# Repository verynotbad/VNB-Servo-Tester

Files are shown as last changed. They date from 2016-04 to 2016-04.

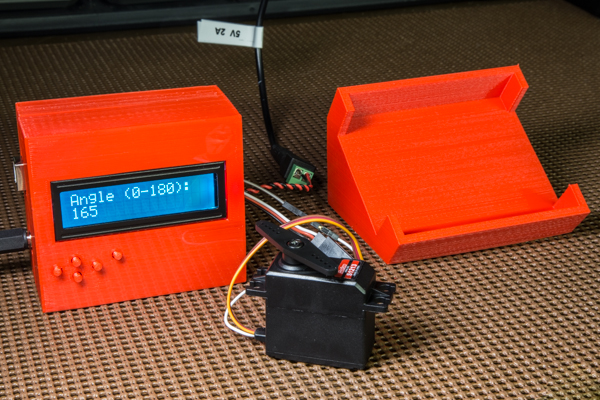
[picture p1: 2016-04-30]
Photos/VNB-Servo-Tester-10.jpg

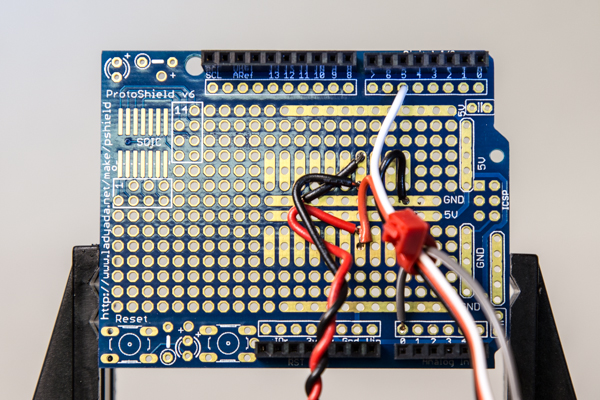
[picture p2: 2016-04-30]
Photos/VNB-Servo-Tester-28.jpg

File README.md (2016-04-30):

# VNB-Servo-Tester

For full details and assembly instructions, visit:
http://verynotbad.tech/projects/servo-tester-calibrator-with-arduino

alt-tag

Using an Arduino UNO, create a interactive device that can test hobby servos, let you calibrate your servo's microcontroller code (e.g. Arduino Sketches) by helping you find the minimum and maximum Pulse Width Modulation (PWM) settings, and even display the internal position of the servo (if your servo is equipped with an analog feedback line).  This project also has instructions and models for 3D Printing an enclosure for your device, letting you create a tool that no makerspace should be without.

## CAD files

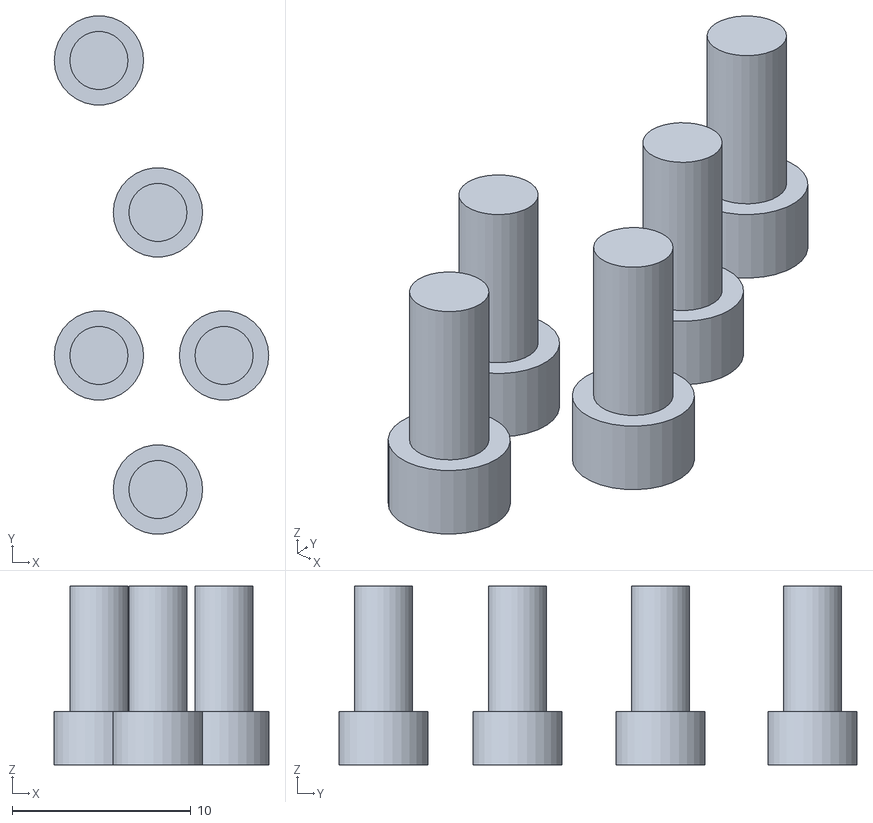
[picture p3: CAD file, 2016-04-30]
3D Model/Enclosure-Buttons.stl
12.0 x 29.0 x 10.0

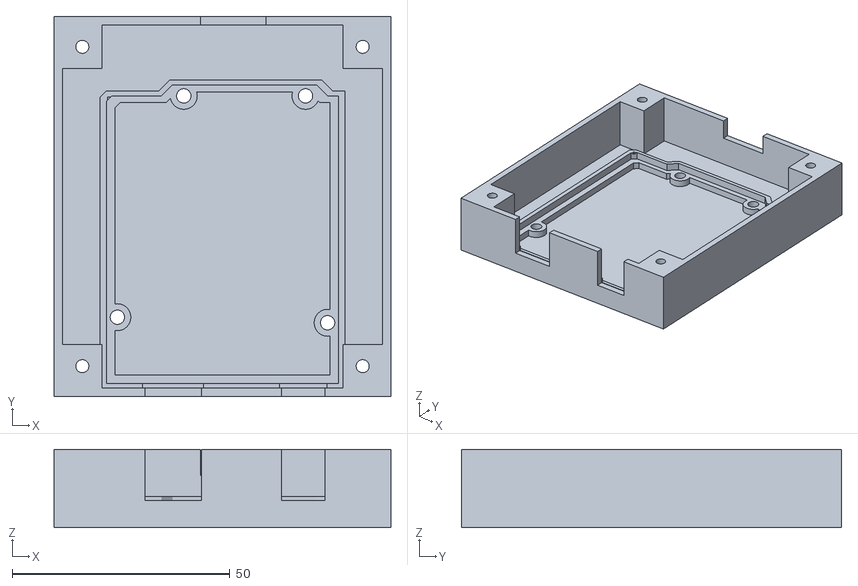
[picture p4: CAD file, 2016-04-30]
3D Model/Enclosure-Bottom.stl
77.3 x 87.3 x 18.0

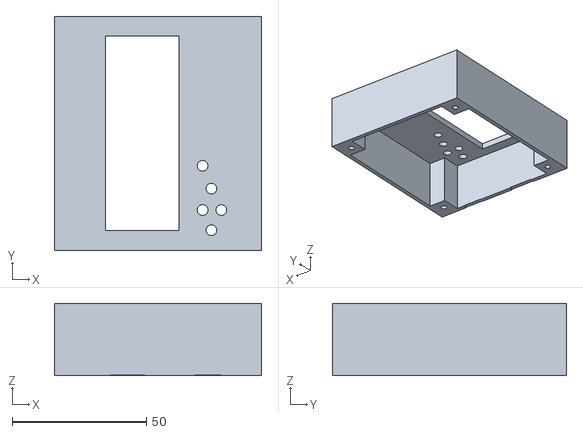
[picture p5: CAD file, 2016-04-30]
3D Model/Enclosure-Top.stl
77.3 x 87.3 x 27.0

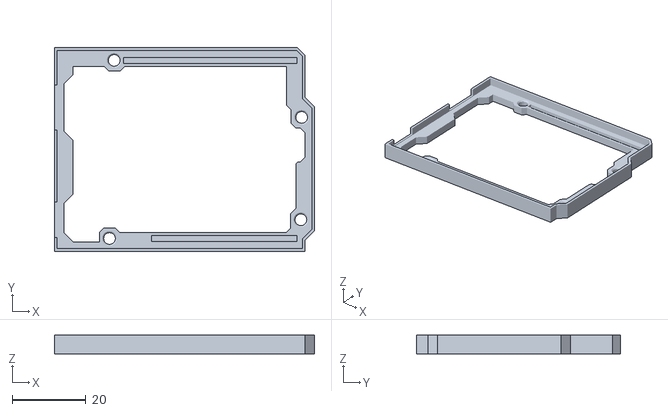
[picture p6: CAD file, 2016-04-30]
3D Model/Arduino_Bumper_0006.stl
70.5 x 55.2 x 5.08

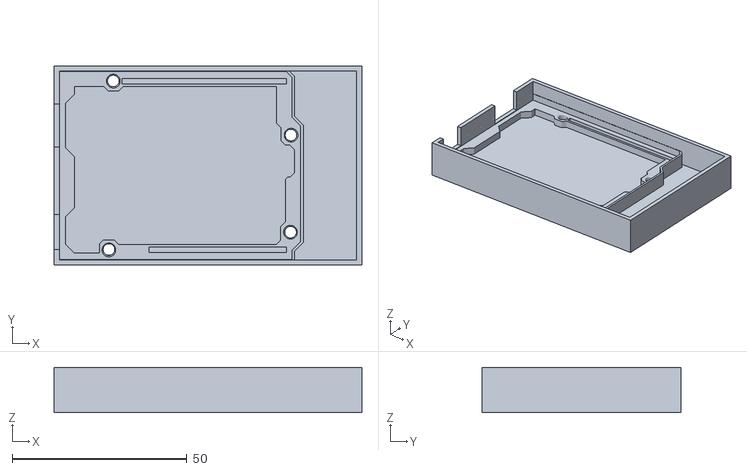
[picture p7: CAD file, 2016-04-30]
3D Model/Servo-Tester-Enclosure.stl
88.0 x 57.0 x 13.0

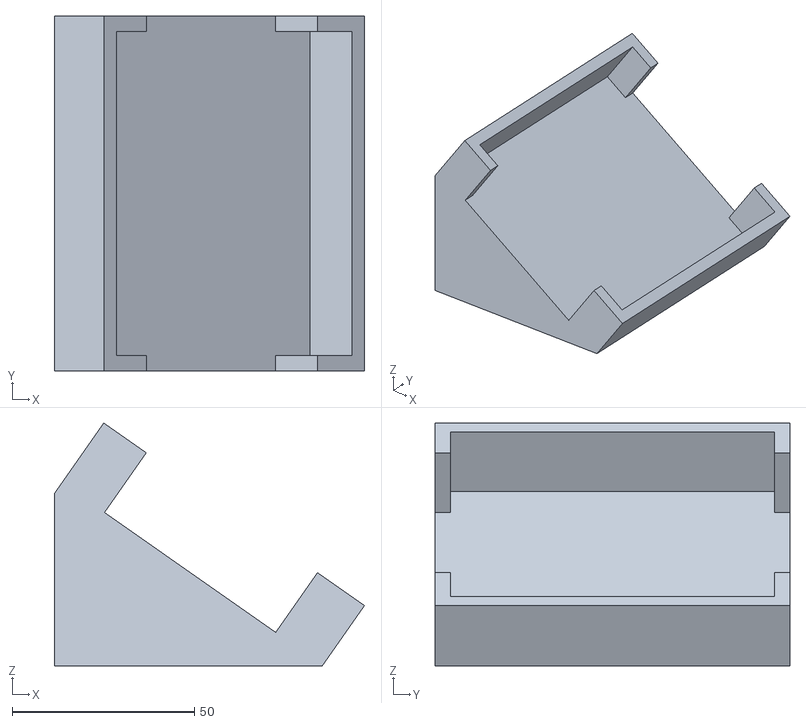
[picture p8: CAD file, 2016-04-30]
3D Model/Servo-Tester-Cradle.stl
85.1 x 97.3 x 66.7

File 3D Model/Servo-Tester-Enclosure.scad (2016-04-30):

use <MCAD/shapes.scad>
include <arduino.scad>

$fn = 30;

wallHeight = 36;

// ----------------------------------------------
// -- Visibility
// ----------------------------------------------

SHOW_ELECTRONICS			= false;

SHOW_TOP 					= false;
SHOW_BOTTOM 				= false;
SHOW_PUSHBUTTONS			= true;

SHOW_CRADLE					= false;

// ----------------------------------------------
// -- Base Parameters
// ----------------------------------------------
wallThickness		= 2.0;
baseThickness		= 3.0;

bottomHeight		= 18.0;

enclosureGapX		= 10.0;
enclosureGapY		= 1.0;

fastenerHoleD		= 3.3;
fastenerSupportX	= 9.0;
fastenerSupportY	= 10.0;

pushButtonH			= 10.0;
pushButtonZ			= 37.5;

bumperOffsetZ		= -2.1;
boardMountingHoleZ	= abs(bumperOffsetZ) + baseThickness + 2;


unoSize = boardDimensions(UNO);
electronicsLengthY = 81.3;
enclosureSizeX = unoSize[0] + (enclosureGapX + wallThickness)*2;
enclosureSizeY = electronicsLengthY + (enclosureGapY + wallThickness)*2;
//enclosureSize = [enclosureSizeX, enclosureSizeY, 0];

offsetX = (wallThickness + enclosureGapX) * -1;
offsetY = (wallThickness + enclosureGapY) * -1;

servoConnectorOpening = [15, 10, 6.1];


echo("Enclosure Size:");
echo("X: ", enclosureSizeX);
echo("Y: ", enclosureSizeY);


// ------------------------------------------------------------
// -- Model Root
// ------------------------------------------------------------

unoSize = boardDimensions(UNO);

	union()
	{

		if (SHOW_ELECTRONICS)
		{
			electronics();
		}

		difference()
		{
			union()
			{
				if (SHOW_TOP)
				{
					translate([0,0,0.1])
					enclosureTop(electronicsLengthY=81.3, topHeight=27, bottomHeight=bottomHeight);
				}

				if (SHOW_BOTTOM)
				{
					translate([0,0,0])
					enclosureBottom(electronicsLengthY=81.3, height=bottomHeight);
				}

				if (SHOW_CRADLE)
				{
					translate([0,0,0])
					enclosureCradle();
				}
			}
			
			
			//enclosureOpenings(height=bottomHeight);



			//arduinoMountingHoles();
			//enclosureOpenings();
			
		}
	}




	
if (SHOW_PUSHBUTTONS)
{
	color("Orange")
	translate([0, 0, pushButtonZ])
	lcdShield(pcb=false, display=false, buttons=false, btnHoleD=4.0, btnHoles=false, resetHole=false, screenHole=false, pushButtons=true, pushButtonH=pushButtonH);
}








// -----------------------------------------------------------------
// -- Modules
// -----------------------------------------------------------------

module enclosureTop(electronicsLengthY, topHeight=15, bottomHeight=10)
{

	enclosureSize = [enclosureSizeX, enclosureSizeY, topHeight];
	cutoutSize    = [enclosureSizeX-(wallThickness*2), enclosureSizeY-(wallThickness*2), topHeight];

	offsetX = (wallThickness + enclosureGapX) * -1;
	offsetY = (wallThickness + enclosureGapY) * -1;
	offsetZ = bottomHeight - baseThickness + bumperOffsetZ;


	difference()
	{
		union()
		{
			difference()
			{
				// -- Outer Walls
				translate([offsetX, offsetY, offsetZ])
				cube(enclosureSize);

				// -- Center Cutout
				translate([offsetX + wallThickness, offsetY + wallThickness, offsetZ - baseThickness])
				cube(cutoutSize);

			}

				// -- Top/Bottom Fastener Support Columns
				fastenerColumns(height=topHeight, offsetZ=offsetZ);
		}

		components( boardType = UNO, component = USB, extension = 5, offset = 0.5);
		components( boardType = UNO, component = POWER, extension = 5, offset = 0.5);

		translate([0, 0, offsetZ])
		lcdShield(pcb=false, display=false, buttons=false, btnHoleD=4.0, btnHoles=true, resetHole=false, screenHole=true);

		fastenerHoles(height=topHeight-2, offsetZ=offsetZ-1, d=3.0);
	}






}


module enclosureBottom(electronicsLengthY, height=10)
{
				translate([0,0,bumperOffsetZ])
				bumper(UNO);
	
/*
	unoSize = boardDimensions(UNO);

	enclosureSizeX = unoSize[0] + (enclosureGapX + wallThickness)*2;
	enclosureSizeY = electronicsLengthY + (enclosureGapY + wallThickness)*2;
*/

	enclosureSize = [enclosureSizeX, enclosureSizeY, height];
	cutoutSize    = [enclosureSizeX-(wallThickness*2), enclosureSizeY-(wallThickness*2), height];

	offsetX = (wallThickness + enclosureGapX) * -1;
	offsetY = (wallThickness + enclosureGapY) * -1;
	offsetZ = -1 * baseThickness + bumperOffsetZ;

	difference()
	{
		union()
		{
			difference()
			{		
				// -- Outer Walls
				translate([offsetX, offsetY, offsetZ])
				cube(enclosureSize);

				// -- Center Cutout
				translate([offsetX + wallThickness, offsetY + wallThickness, offsetZ + baseThickness])
				cube(cutoutSize);


			}

			// -- Top/Bottom Fastener Support Columns
			fastenerColumns(height=height, offsetZ=offsetZ);

		}

		components( boardType = UNO, component = USB, extension = 5, offset = 0.5);
		components( boardType = UNO, component = POWER, extension = 5, offset = 0.5);

		// -- Hole for Servo Connectors
		translate([unoSize[0]/2-5, 81.0, height+offsetZ-servoConnectorOpening[2] + 0.1])
		cube(servoConnectorOpening);


		fastenerHoles(height=height+2, offsetZ=offsetZ-1, d=3.0);

		// -- Arduino Mounting Holes
			for(i = boardHoles[UNO] ) 
			{
    			translate([i[0], i[1], boardMountingHoleZ*-1])
    			cylinder(d=3.3, h=boardMountingHoleZ);
  			}

	}


	
}


module enclosureCradle()
{
	enclosureSize = [enclosureSizeX, enclosureSizeY, 100];

	offsetX = (wallThickness + enclosureGapX) * -1;
	offsetY = (wallThickness + enclosureGapY) * -1;
	offsetZ = -1 * baseThickness + bumperOffsetZ;

	cradleHeight    = 60.0;
	baseHeight	 	= 30;
	wallThickness 	= 5.0;
	cutoutDepth 	= baseHeight-20.0;
	cutoutGap		= 0.75;
	sideCutoutX		= enclosureSizeX-20;
	sideCutoutOffset= 10;

	cutoutDepthAdder = 15;

	rotate([0,35,0])
	difference() 
	{
		union()
		{ 
			// -- Cradle
			color("Red")
			translate([offsetX-wallThickness, offsetY-wallThickness, offsetZ-cutoutDepth])
			rotate([0,0,0])
			cube([enclosureSize[0]+(wallThickness*2), enclosureSize[1]+(wallThickness*2), baseHeight-cutoutDepthAdder], center=false);

			rotate([0,-35,0])
			intersection() 
			{
			
				color("Red")
				translate([offsetX - enclosureSize[0], offsetY-wallThickness, cradleHeight*-1+3])
				rotate([0,0,0])
				cube([enclosureSize[0]*2, enclosureSize[1]+(wallThickness*2), cradleHeight], center=false);

				color("Red")
				rotate([0,35,0])
				translate([offsetX-wallThickness, offsetY-wallThickness, offsetZ-cutoutDepth-100])
				cube([enclosureSize[0]+(wallThickness*2), enclosureSize[1]+(wallThickness*2), 110], center=false);

				translate([-27.5,-50,-80])
				cube([100,200,100]);

			}


		}

		color("Orange")
		translate([offsetX-cutoutGap, offsetY-cutoutGap, offsetZ-cutoutDepthAdder])
		rotate([0,0,0])
		cube([enclosureSize[0]+(cutoutGap*2), enclosureSize[1]+(cutoutGap*2), 100], center=false);

		// -- Side Cutouts for Wires
		color("Orange")
		translate([offsetX-cutoutGap + sideCutoutOffset, offsetY-cutoutGap-enclosureSize[1]/2, offsetZ-cutoutDepthAdder])
		rotate([0,0,0])
		cube([sideCutoutX, enclosureSize[1]*2+(cutoutGap*2), 100], center=false);



	}


}


module fastenerColumns(height, offsetZ)
{
	offsetX = (wallThickness + enclosureGapX) * -1;
	offsetY = (wallThickness + enclosureGapY) * -1;
	//offsetZ = -1 * baseThickness + bumperOffsetZ;

	supportXL = enclosureGapX*-1;
	supportXR = enclosureSizeX + offsetX - fastenerSupportX - wallThickness;
	supportYB = enclosureGapY*-1;
	supportYT = enclosureSizeY + offsetY - fastenerSupportY - wallThickness;

	// -- Top/Bottom Fastener Support Columns
	translate([supportXL, supportYB, offsetZ])
	cube([fastenerSupportX, fastenerSupportY, height]);

	translate([supportXL,supportYT, offsetZ])
	cube([fastenerSupportX, fastenerSupportY, height]);

	translate([supportXR, supportYB, offsetZ])
	cube([fastenerSupportX, fastenerSupportY, height]);

	translate([supportXR,supportYT, offsetZ])
	cube([fastenerSupportX, fastenerSupportY, height]);

}

module fastenerHoles(height, offsetZ=0, d=3.0)
{
	offsetX = (wallThickness + enclosureGapX) * -1;
	offsetY = (wallThickness + enclosureGapY) * -1;
	//offsetZ = -1 * baseThickness + bumperOffsetZ;

	supportXL = enclosureGapX*-1 + fastenerSupportX/2;
	supportXR = enclosureSizeX + offsetX - fastenerSupportX - wallThickness + fastenerSupportX/2;
	supportYB = enclosureGapY*-1 + fastenerSupportY/2;
	supportYT = enclosureSizeY + offsetY - fastenerSupportY - wallThickness + fastenerSupportY/2;


	translate([supportXL, supportYB, offsetZ])
	cylinder(d=d, h=height);

	translate([supportXL, supportYT, offsetZ])
	cylinder(d=d, h=height);

	translate([supportXR, supportYB, offsetZ])
	cylinder(d=d, h=height);

	translate([supportXR, supportYT, offsetZ])
	cylinder(d=d, h=height);

}


module electronics()
{
	// -- Arduino Board
	translate([0,0,0])
	arduino(UNO);

	// -- Prototype Shield
	translate([0,0,13.0])
	union()
	{
		color("SteelBlue")
		boardShape(UNO);

		components( boardType = UNO, component = HEADER_F );
	}

	// -- LCD Shield
	translate([0, 0, 25.3])
	lcdShield();
}
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

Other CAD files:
3D Model/pins.scad
3D Model/arduino.scad

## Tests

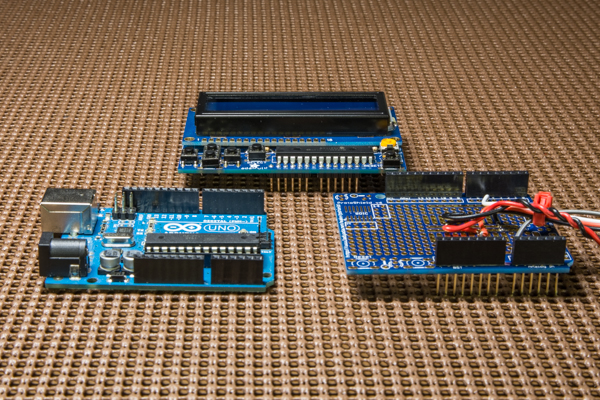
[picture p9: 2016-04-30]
Photos/VNB-Servo-Tester-34.jpg

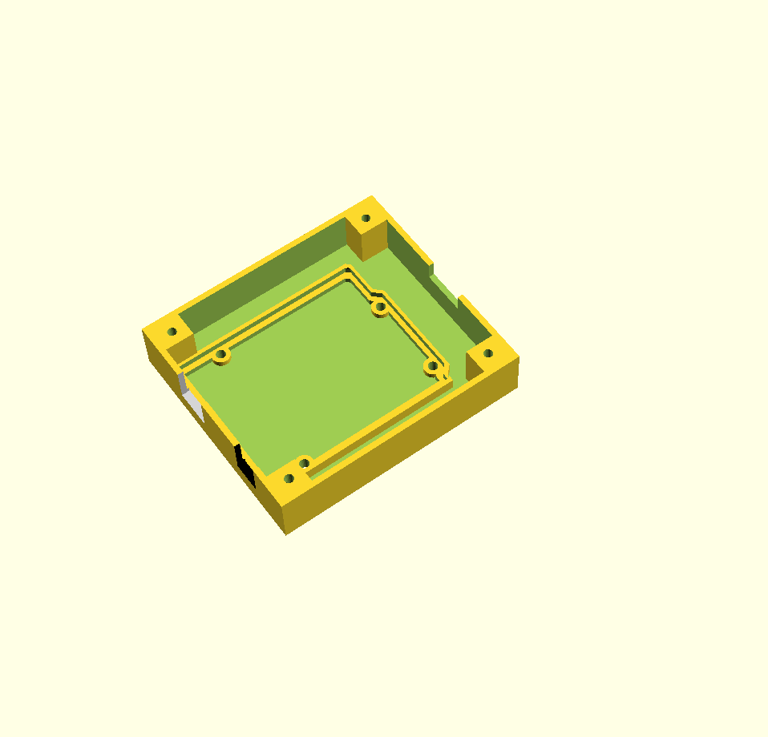
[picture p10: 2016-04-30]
Docs/Servo Tester - 3D Bottom.png

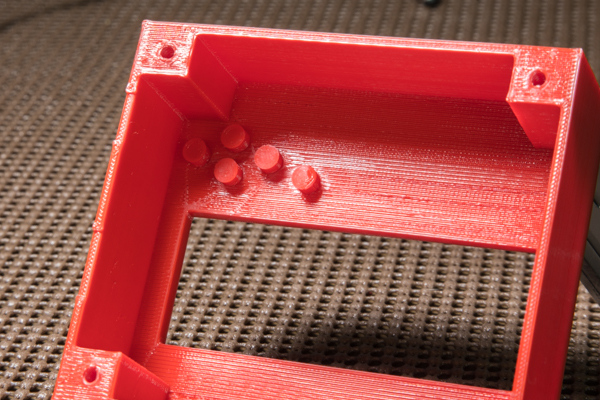
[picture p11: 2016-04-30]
Photos/VNB-Servo-Tester-33.jpg

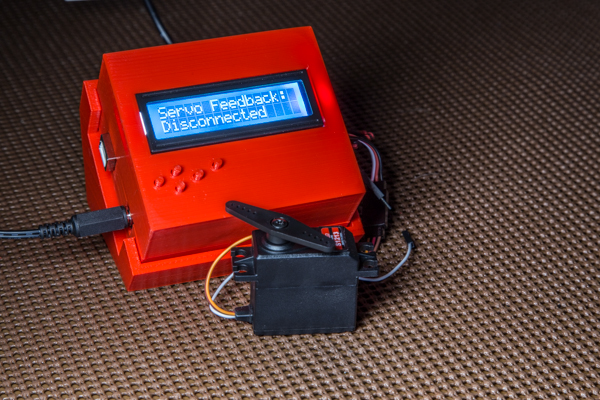
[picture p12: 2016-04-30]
Photos/VNB-Servo-Tester-8.jpg

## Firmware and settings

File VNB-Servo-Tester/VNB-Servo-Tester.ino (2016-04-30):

/**********************************************
 * Servo Tester
 * Copyright (c) 2016 Very Not Bad Prototypes
 * All Rights Reserved
 * 
 * http://www.verynotbad.tech
 * 
 * This code is a Servo Tester using an
 * Arduino Microcontroller and an Adafruit
 * LCD Shield.
 * 
 * Tests the following for hobby servos: 
 *    - PWM Min/Max
 *    - Feedback Values
 *    - Angles
 *    
 * Revision 01 - Initial Version
************************************************/

#include <Wire.h>
#include <Servo.h>
#include <Adafruit_MCP23017.h>
#include <Adafruit_RGBLCDShield.h>



// These #defines make it easy to set the backlight color
#define RED 0x1
#define YELLOW 0x3
#define GREEN 0x2
#define TEAL 0x6
#define BLUE 0x4
#define VIOLET 0x5
#define WHITE 0x7

#define MODE_ANGLE        0
#define MODE_PWM_MIN      1 
#define MODE_PWM_MAX      2
#define MODE_FEEDBACK     3
#define MODE_PULLUP       4

#define COLOR_INTRO       GREEN
#define COLOR_ATTACHED    RED
#define COLOR_DETACHED    WHITE
#define COLOR_ERROR       YELLOW

#define INTRO_LINE1       "VNB Servo Tester"
#define INTRO_LINE2       "v1.0"
#define INTRO_DURATION    2500

#define TITLE_ANGLE       "Angle (0-180):"
#define TITLE_PWM_MIN     "Min PWM (uSec):"
#define TITLE_PWM_MAX     "Max PWM (uSec):"
#define TITLE_FEEDBACK    "Servo Feedback:"
#define TITLE_PULLUP      "Pullup Resistor:"
#define LINE2_ENABLED     "Enabled"
#define LINE2_DISABLED    "Disabled"
#define EMPTY_LINE        "                " // 16 spaces



#define FEEDBACK_VALUE_THRESHOLD  1
#define FEEDBACK_TIME_THRESHOLD   1000
#define FEEDBACK_DISCON_THRESHOLD 1010
#define MAX_FEEDBACK              1023


#define ANGLE_INCREMENT           5
#define PWM_INCREMENT             50

#define PWM_MIN                   PWM_INCREMENT
#define PWM_MAX                   5000

#define ANGLE_MIN                 0
#define ANGLE_MAX                 180

#define ERROR_DURATION            1000

#define SERVO_PIN_DATA            5
#define SERVO_PIN_FEEDBACK        A0



// The shield uses the I2C SCL and SDA pins. On classic Arduinos
// this is Analog 4 and 5 so you can't use those for analogRead() anymore
// However, you can connect other I2C sensors to the I2C bus and share
// the I2C bus.
Adafruit_RGBLCDShield lcd = Adafruit_RGBLCDShield();

// Declare a Servo, but don't attach it until the user chooses to
Servo servo;
int   pwmMin            = 1000;
int   pwmMax            = 2000;
int   angle             = (ANGLE_MIN + ANGLE_MAX)/2;
int   feedback          = -1000;
int   lastFeedbackTime  = 0;
bool  pullupEnabled     = true;

// Set the initial mode
uint8_t mode = MODE_ANGLE;

/* -------------------------------------------
 *  Setup
 *     - Initialize LCD
 *     - Initialize Servo Pins
 * ------------------------------------------- */
void setup() 
{

  // Setup the LCD's number of columns and rows: 
  lcd.begin(16, 2);

  // Print Intro Message to LCD
  lcd.print(INTRO_LINE1);
  lcd.setCursor(0,1);
  lcd.print(INTRO_LINE2);
  lcd.setBacklight(COLOR_INTRO);

  // Hold Intro Message for a short duration
  delay(INTRO_DURATION);

  // Setup Pin Modes
  pinMode(SERVO_PIN_DATA, OUTPUT);
  pinMode(SERVO_PIN_FEEDBACK, INPUT);
  if (pullupEnabled)
    digitalWrite(SERVO_PIN_FEEDBACK, HIGH); // Enabled internal pullup resistor

  // Setup ANGLE Mode
  lcd.setBacklight(COLOR_DETACHED);
  changeToModeAngle(); 

  
}



/* ----------------------------------------------------
 *  Loop
 *     - Read Button State
 *     - If Select pressed, toggle attach/detach
 *     - If left/right pressed, change mode
 *     - Execute Mode-specific behavior
 * --------------------------------------------------- */
void loop() 
{

  uint8_t buttons = lcd.readButtons();

  if (buttons & BUTTON_SELECT)
  {
    toggleAttachment();
 
    // Clear all button presses
    buttons = 0;    
  }

  
  if (buttons & (BUTTON_LEFT | BUTTON_RIGHT))
  {
    changeMode(buttons);   

    // Clear all button presses
    buttons = 0;

    delay(300);
  }

  

  if (mode == MODE_ANGLE)
  {
    runModeAngle(buttons);
  }

  else if (mode == MODE_FEEDBACK)
  {
    runModeFeedback();
  }
  
  else if (mode == MODE_PWM_MIN)
  {
    runModePwmMin(buttons);
  }
  
  else if (mode == MODE_PWM_MAX)
  {
    runModePwmMax(buttons);
  }

  else if (mode == MODE_PULLUP)
  {
    runModePullup(buttons);
  }

}


void toggleAttachment()
{
   if (servo.attached())
    {
      servo.detach();
      lcd.setBacklight(COLOR_DETACHED);
    }
    else 
    {
      servo.attach(SERVO_PIN_DATA, pwmMin, pwmMax);
      servo.write(angle);
      lcd.setBacklight(COLOR_ATTACHED);
    }

    delay(500);
}



void flashErrorBacklight()
{
   lcd.setBacklight(COLOR_ERROR);
   delay(ERROR_DURATION);
  
   if (servo.attached())
    {
      lcd.setBacklight(COLOR_ATTACHED);
    }
    else 
    {
      lcd.setBacklight(COLOR_DETACHED);
    }
  
}


/*
 * Change Mode (upon left/right button press):
 * Mode change logic is as follows:
 *        - If Mode == ANGLE:
 *           - LEFT: Do nothing
 *           - RIGHT: Change to FEEDBACK
 *        - If Mode == FEEDBACK
 *           - LEFT: Change to ANGLE
 *           - RIGHT: Change to PWM_MIN
 *        - If Mode == PWM_MIN:
 *           - LEFT: Change to Feedback
 *           - RIGHT: Change to PWM_MAX
 *        - If Mode == PWM_MAX:
 *           - LEFT: Change to PWM_MIN
 *           - RIGHT: Change to PULLUP
 *        - If Mode == PULLUP
 *           - LEFT: Change to PWM_MAX
 *           - RIGHT: Do Nothing
 */
void changeMode(uint8_t buttons)
{
  
  // --
  // -- Current Mode: ANGLE
  // --
  if (mode == MODE_ANGLE)
  {
  
    if (buttons & BUTTON_LEFT) 
    {
      // -- Do Nothing    
    }
    
    // -- Change to: Feedback
    if (buttons & BUTTON_RIGHT) 
    {
      changeToModeFeedback();    
    }

  }

  // --
  // -- Current Mode: FEEDBACK
  // --
  else if (mode == MODE_FEEDBACK)
  {
    if (buttons & BUTTON_LEFT) 
    {
      changeToModeAngle();    
      feedback = -1000;     // Force a refresh if we come back to this mode
    }

    if (buttons & BUTTON_RIGHT) 
    {
      changeToModePwmMin();    
      feedback = -1000;    // Force a refresh if we come back to this mode
    }

  }

  // --
  // -- Current Mode: PWM_MIN
  // --
  else if (mode == MODE_PWM_MIN)
  {
    if (buttons & BUTTON_LEFT) 
    {
      changeToModeFeedback();    
    }

    if (buttons & BUTTON_RIGHT) 
    {
      changeToModePwmMax();    

    }


  }

  // --
  // -- Current Mode: PWM_MAX
  // --
  else if (mode == MODE_PWM_MAX)
  {
    if (buttons & BUTTON_LEFT) 
    {
      changeToModePwmMin();    
    }

    if (buttons & BUTTON_RIGHT) 
    {
      changeToModePullup();    

    }



  }

  
  // --
  // -- Current Mode: PULLUP
  // --
  else if (mode == MODE_PULLUP)
  {
    if (buttons & BUTTON_LEFT) 
    {
      changeToModePwmMax();    
    }

    if (buttons & BUTTON_RIGHT) 
    {
      // -- Do Nothing   

    }



  }


}

void changeToModeAngle()
{
      lcd.clear();
      lcd.setCursor(0,0);
      lcd.print(TITLE_ANGLE);
      mode = MODE_ANGLE;

      lcd.setCursor(0,1);
      lcd.print(EMPTY_LINE);
      lcd.setCursor(0,1);
      lcd.print(angle);

}

void changeToModeFeedback()
{
      lcd.clear();
      lcd.setCursor(0,0);
      lcd.print(TITLE_FEEDBACK);
      mode = MODE_FEEDBACK;

      lcd.setCursor(0,1);
      lcd.print(EMPTY_LINE);
}

void changeToModePwmMin()
{
      lcd.clear();
      lcd.setCursor(0,0);
      lcd.print(TITLE_PWM_MIN);
      mode = MODE_PWM_MIN;

      lcd.setCursor(0,1);
      lcd.print(EMPTY_LINE);
      lcd.setCursor(0,1);
      lcd.print(pwmMin);

}

void changeToModePwmMax()
{
      lcd.clear();
      lcd.setCursor(0,0);
      lcd.print(TITLE_PWM_MAX);
      mode = MODE_PWM_MAX;

      lcd.setCursor(0,1);
      lcd.print(EMPTY_LINE);
      lcd.setCursor(0,1);
      lcd.print(pwmMax);

}


void changeToModePullup()
{
      lcd.clear();
      lcd.setCursor(0,0);
      lcd.print(TITLE_PULLUP);
      mode = MODE_PULLUP;

    lcd.setCursor(0,1);
    lcd.print(EMPTY_LINE);
    lcd.setCursor(0,1);
    if (pullupEnabled)
    {
      lcd.print(LINE2_ENABLED);
    }
    else 
    {
      lcd.print(LINE2_DISABLED);
    }

}

// --------------------------------------------------------------

void runModeAngle(uint8_t buttons)
{

  int increment = 0;
  
  if (buttons & BUTTON_UP)
  {
    increment = ANGLE_INCREMENT;
  }

  else if (buttons & BUTTON_DOWN)
  {
    increment = ANGLE_INCREMENT * -1;
  }


  if (increment != 0)
  {
    angle += increment;

    if (angle < ANGLE_MIN)
    {
      angle = ANGLE_MIN;
      flashErrorBacklight();
    }

    if (angle > ANGLE_MAX)
    {
      angle = ANGLE_MAX;
      flashErrorBacklight();
    }

    lcd.setCursor(0,1);
    lcd.print(EMPTY_LINE);
    lcd.setCursor(0,1);
    lcd.print(angle);

    if (servo.attached())
    {
      servo.write(angle);
    }
  }

  delay(100);
}


void runModeFeedback()
{
  int time = millis();
  int deltaT = time - lastFeedbackTime;

  int sensorValue = analogRead(SERVO_PIN_FEEDBACK);
  int deltaV      = abs(sensorValue - feedback);

  float pctValue  = (float)sensorValue / 1024.0;
  //int   pctInt    = (int)(pctValue * 100);

  bool updateLCD = (deltaV > FEEDBACK_VALUE_THRESHOLD) || 
                   ((deltaT > FEEDBACK_TIME_THRESHOLD) && (deltaV != 0));

  if ((sensorValue > FEEDBACK_DISCON_THRESHOLD))
  {
    if (feedback != MAX_FEEDBACK)
    {
      lcd.setCursor(0,1);
      lcd.print(EMPTY_LINE);
    
      lcd.setCursor(0,1);
      lcd.print("Disconnected");
  
      feedback = MAX_FEEDBACK;
    }

    delay(100);
    updateLCD = false;
  }

  
  
  if (updateLCD)
  {
    lcd.setCursor(0,1);
    lcd.print(EMPTY_LINE);
  
    lcd.setCursor(0,1);
    lcd.print(sensorValue);

    
    lcd.setCursor(12,1);
    lcd.print(pctValue);

    feedback = sensorValue;
    lastFeedbackTime = time;

    delay(100);
  }

}

void runModePwmMin(uint8_t buttons)
{

  int increment = 0;

  if (!servo.attached())
  {
    if (buttons & BUTTON_UP)
    {
      increment = PWM_INCREMENT;
    }
    
    else if (buttons & BUTTON_DOWN)
    {
      increment = PWM_INCREMENT * -1;
    }
  }

  else if (buttons & (BUTTON_UP | BUTTON_DOWN))
  {
    lcd.setCursor(7,1);
    lcd.print("LOCKED");
    delay(ERROR_DURATION);
    lcd.setCursor(7,1);
    lcd.print("      ");
    
  }



  if (increment != 0)
  {
    pwmMin += increment;

    if (pwmMin < PWM_MIN)
    {
      pwmMin = PWM_MIN;
      flashErrorBacklight();
    }

    if (pwmMin >= pwmMax)
    {
      pwmMin = pwmMax - PWM_INCREMENT;
      flashErrorBacklight();
    }

    lcd.setCursor(0,1);
    lcd.print(EMPTY_LINE);
    lcd.setCursor(0,1);
    lcd.print(pwmMin);

  }

  delay(100);
}

void runModePwmMax(uint8_t buttons)
{

  int increment = 0;

  if (!servo.attached())
  {
    if (buttons & BUTTON_UP)
    {
      increment = PWM_INCREMENT;
    }
    
    else if (buttons & BUTTON_DOWN)
    {
      increment = PWM_INCREMENT * -1;
    }
  }

  else if (buttons & (BUTTON_UP | BUTTON_DOWN))
  {
    lcd.setCursor(7,1);
    lcd.print("LOCKED");
    delay(ERROR_DURATION);
    lcd.setCursor(7,1);
    lcd.print("      ");
  }


  if (increment != 0)
  {
    pwmMax += increment;

    if (pwmMax <= pwmMin)
    {
      pwmMax = pwmMin + PWM_INCREMENT;
      flashErrorBacklight();
    }

    if (pwmMax > PWM_MAX)
    {
      pwmMax = PWM_MAX;
      flashErrorBacklight();
    }

    lcd.setCursor(0,1);
    lcd.print(EMPTY_LINE);
    lcd.setCursor(0,1);
    lcd.print(pwmMax);

  }

  delay(100);
}

void runModePullup(uint8_t buttons)
{


  if (buttons & (BUTTON_UP | BUTTON_DOWN))
  {
    pullupEnabled = !pullupEnabled;

    if (pullupEnabled)
    {
      digitalWrite(SERVO_PIN_FEEDBACK, HIGH);
    }
    else 
    {
      digitalWrite(SERVO_PIN_FEEDBACK, LOW);
    }


    lcd.setCursor(0,1);
    lcd.print(EMPTY_LINE);
    lcd.setCursor(0,1);
    if (pullupEnabled)
    {
      lcd.print(LINE2_ENABLED);
    }
    else 
    {
      lcd.print(LINE2_DISABLED);
    }

    
  }


 
  

  delay(100);
}
